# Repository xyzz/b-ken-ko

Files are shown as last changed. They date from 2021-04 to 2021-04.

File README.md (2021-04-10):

# b\*ken\*ko

A gummyworm mount case based on [Bakeneko 60](https://github.com/kkatano/bakeneko-60) by [kkatano](https://github.com/kkatano)

## Notes

* Case holes/threads for the daughterboard are a bit shallow, you might have to use 3mm M3 screws. Or increase hole depth in the model.
* The reworked PCB is using STM32F103, you will need an ST-Link ($2 from aliexpress) to flash the bootloader if you get it made.
* Production files for PCB and daughterboard use JLCPCB assembly, JLCPCB will not solder JST connectors for you so they are not included into the files, you will have to hand-solder the connector. If you use a different fab, make sure the JST connector is included into the BOM and position file (or you'll get semi-assembled PCBs).
* O-ring spec is AS568-263 (ID 7.234", CS 0.139" / ID 183.74mm, CS 3.53mm).
* As we're not allowed to use the Unikorn mounting points, note that the PCB mounting points are not compatible with Unikorn, neither the Unikorn-compatible PCBs (such as plain60-flex) are compatible with this case

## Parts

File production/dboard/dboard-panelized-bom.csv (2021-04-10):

Comment | Designator | Footprint | LCSC
Conn_01x04 | J2 | random-keyboard-parts:JST-SR-4
5.1k | R1,R2 | Resistor_SMD:R_0603_1608Metric | C23186
Mount-M2 | MH1,MH2 | MountingHole:MountingHole_3.2mm_M3_Pad_Via
1M | R3 | Resistor_SMD:R_0805_2012Metric | C17514
4.7n | C1 | Capacitor_SMD:C_0603_1608Metric | C53987
HRO-TYPE-C-31-M-12 | J1 | Type-C:HRO-TYPE-C-31-M-12-jlc | C165948

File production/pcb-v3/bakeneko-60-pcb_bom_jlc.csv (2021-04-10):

Comment | Designator | Footprint | LCSC Part #
1u | C1,C2,C10 | C_0603_1608Metric | C15849
20p | C4,C5 | C_0603_1608Metric | C1648
100n | C6,C7,C8,C9,C11,C3 | C_0603_1608Metric | C14663
10u | C12 | C_0603_1608Metric | C19702
1N4148 | D63,D62,D61,D60,D59,D58,D57,D56,D55,D54,D53,D52,D51,D50,D49,D48,D47,D46,D45,D44,D43,D42,D41,D40,D39,D38,D37,D36,D35,D34,D33,D32,D31,D30,D29,D28,D27,D26,D25,D24,D23,D22,D21,D20,D19,D18,D17,D16,D15,D14,D13,D12,D11,D10,D9,D8,D7,D6,D5,D4,D3,D2,D1 | D_SOD-123 | C81598
500mA | F1 | Fuse_1206_3216Metric | C369159
10k | R1 | R_0603_1608Metric | C25804
1.5k | R2 | R_0603_1608Metric | C22843
SRV05-4 | U1 | SOT-23-6 | C85364
XC6206P332MR | U2 | SOT-23 | C5446
STM32F103C8Tx | U3 | LQFP-48_7x7mm_P0.5mm | C8304
8MHz | Y1 | Crystal_SMD_5032-2Pin_5.0x3.2mm | C115962

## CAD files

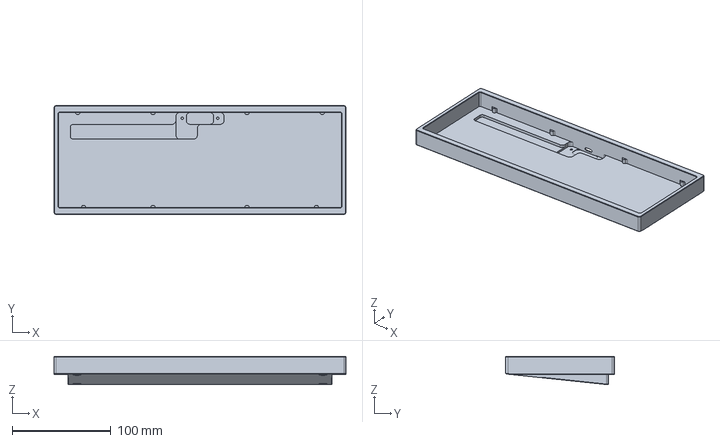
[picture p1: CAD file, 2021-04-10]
case/Case.stp
295.7 x 110.2 x 28.8 mm

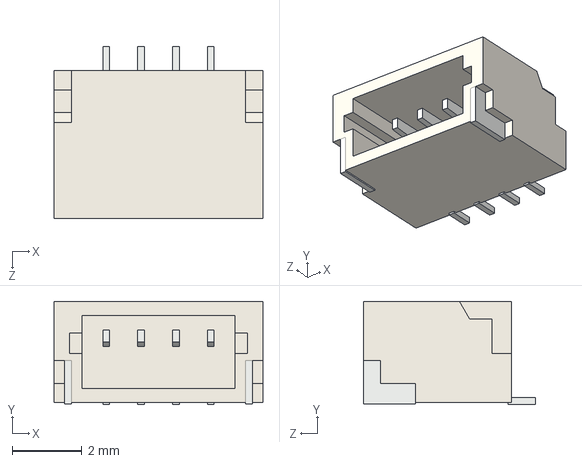
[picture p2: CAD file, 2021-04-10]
pcb/JST_SM04B-SRSS-TB.STEP
6.00 x 2.96 x 4.95 mm

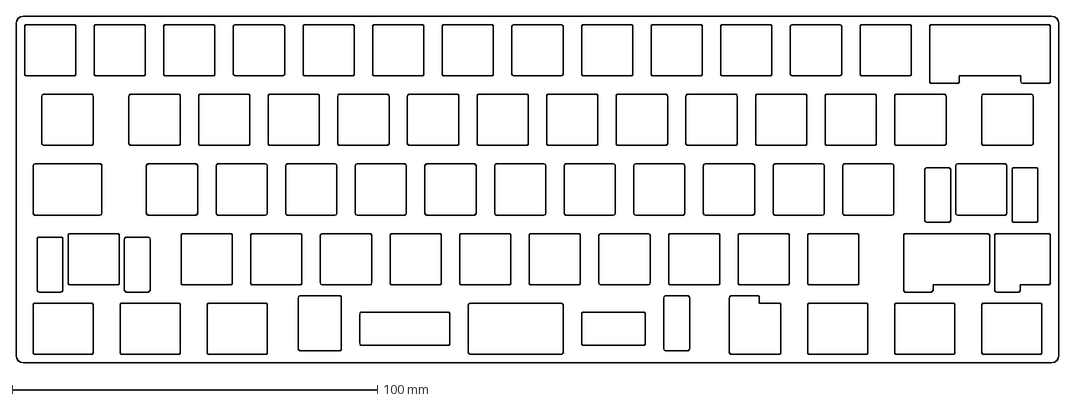
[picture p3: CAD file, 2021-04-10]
plate.dxf
285.4 x 94.8 mm

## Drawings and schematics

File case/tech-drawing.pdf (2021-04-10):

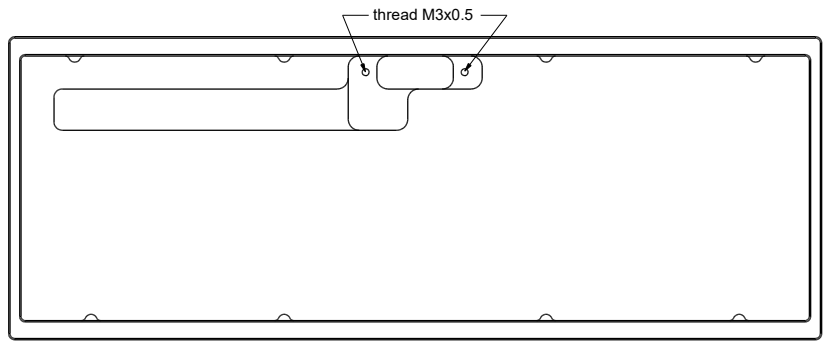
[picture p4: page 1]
thread M3x0.5

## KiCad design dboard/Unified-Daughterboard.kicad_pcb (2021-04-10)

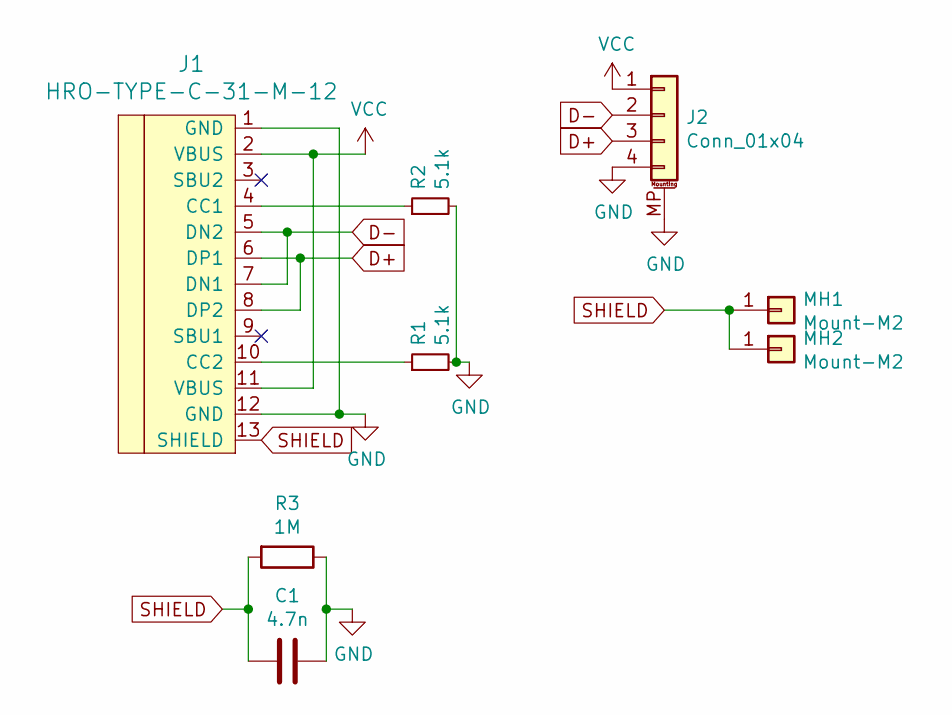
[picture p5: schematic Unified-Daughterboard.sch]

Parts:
C1: 4.7n; C_0603_1608Metric; LCSC C53987
J1: HRO-TYPE-C-31-M-12; HRO-TYPE-C-31-M-12-jlc; LCSC C165948
J2: Conn_01x04; JST-SR-4
MH1, MH2: Mount-M2; MountingHole_3.2mm_M3_Pad_Via
R1, R2: 5.1k; R_0603_1608Metric; LCSC C23186
R3: 1M; R_0805_2012Metric; LCSC C17514

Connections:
D+: J1.6 (DP1), J1.8 (DP2), J2.3
D-: J1.5 (DN2), J1.7 (DN1), J2.2
GND: C1.1, J1.1 (GND), J1.12 (GND), J2.4, J2.MP (MountPin), R1.2, R2.2, R3.1
unnamed: J1.4 (CC1), R2.1
unnamed: J1.10 (CC2), R1.1
SHIELD: C1.2, J1.13 (SHIELD), MH1.1, MH2.1, R3.2
VCC: J1.2 (VBUS), J1.11 (VBUS), J2.1

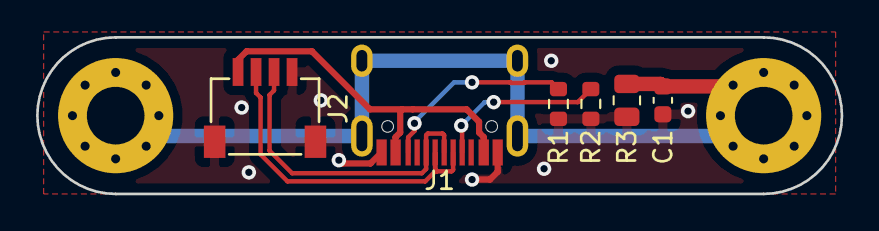
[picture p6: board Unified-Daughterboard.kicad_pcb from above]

Board: 2 copper layers, 44.7 x 8.7 mm, 8 parts (0 on the bottom side), 7 nets.

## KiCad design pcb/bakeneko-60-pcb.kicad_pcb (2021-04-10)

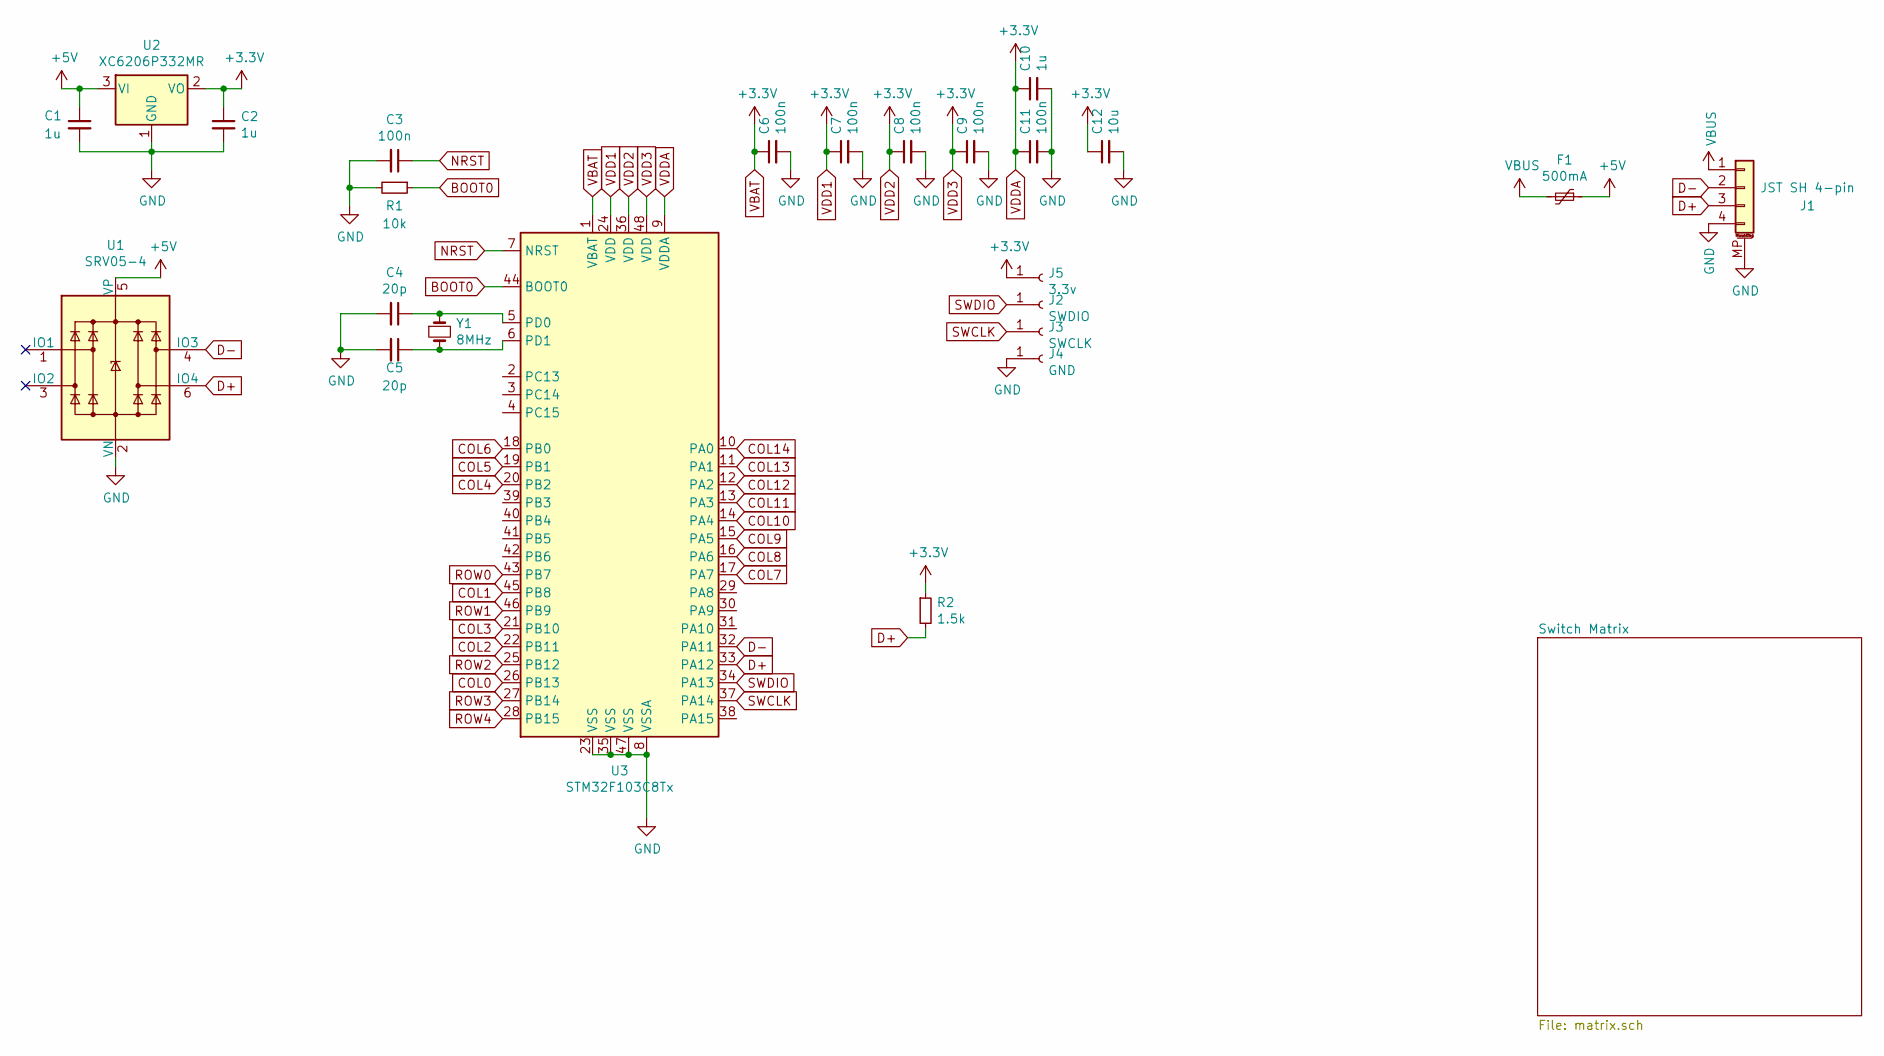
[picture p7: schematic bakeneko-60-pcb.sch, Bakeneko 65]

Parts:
C1, C2, C10: 1u; C_0603_1608Metric; JLC C15849
C3, C6, C7, C8, C9, C11: 100n; C_0603_1608Metric; JLC C14663
C4, C5: 20p; C_0603_1608Metric; JLC C1648
C12: 10u; C_0603_1608Metric; JLC C19702
F1: 500mA; Fuse_1206_3216Metric; JLC C369159
J1: JST SH 4-pin; JST_SH_SM04B-SRSS-TB_1x04-1MP_P1.00mm_Horizontal
J2: SWDIO; TestPoint_Pad_D1.5mm
J3: SWCLK; TestPoint_Pad_D1.5mm
J4: GND; TestPoint_Pad_D1.5mm
J5: 3.3v; TestPoint_Pad_D1.5mm
R1: 10k; R_0603_1608Metric; JLC C25804
R2: 1.5k; R_0603_1608Metric; JLC C22843
U1: SRV05-4; SOT-23-6; JLC C85364
U2: XC6206P332MR; SOT-23; JLC C5446
U3: STM32F103C8Tx; LQFP-48_7x7mm_P0.5mm; JLC C77979
Y1: 8MHz; Crystal_SMD_5032-2Pin_5.0x3.2mm; JLC C115962

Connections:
+5V: C1.1, F1.1, U1.5 (VP), U2.3 (VI)
BOOT0: R1.1, U3.44 (BOOT0)
COL0: U3.26 (PB13); also elsewhere on the board
COL1: U3.45 (PB8); also elsewhere on the board
COL2: U3.22 (PB11); also elsewhere on the board
COL3: U3.21 (PB10); also elsewhere on the board
COL4: U3.20 (PB2); also elsewhere on the board
COL5: U3.19 (PB1); also elsewhere on the board
COL6: U3.18 (PB0); also elsewhere on the board
COL7: U3.17 (PA7); also elsewhere on the board
COL8: U3.16 (PA6); also elsewhere on the board
COL9: U3.15 (PA5); also elsewhere on the board
COL10: U3.14 (PA4); also elsewhere on the board
COL11: U3.13 (PA3); also elsewhere on the board
COL12: U3.12 (PA2); also elsewhere on the board
COL13: U3.11 (PA1); also elsewhere on the board
COL14: U3.10 (PA0); also elsewhere on the board
D+: J1.3, R2.2, U1.6 (IO4), U3.33 (PA12)
D-: J1.2, U1.4 (IO3), U3.32 (PA11)
GND: C1.2, C2.2, C3.2, C4.2, C5.2, C6.2, C7.2, C8.2, C9.2, C10.2, C11.2, C12.2, J1.4, J1.MP (MountPin), J4.1, R1.2, U1.2 (VN), U2.1 (GND), U3.8 (VSSA), U3.23 (VSS), U3.35 (VSS), U3.47 (VSS)
NRST: C3.1, U3.7 (NRST)
unnamed: C4.1, U3.5 (PD0), Y1.1
unnamed: C5.1, U3.6 (PD1), Y1.2
ROW0: U3.43 (PB7); also elsewhere on the board
ROW1: U3.46 (PB9); also elsewhere on the board
ROW2: U3.25 (PB12); also elsewhere on the board
ROW3: U3.27 (PB14); also elsewhere on the board
ROW4: U3.28 (PB15); also elsewhere on the board
SWCLK: J3.1, U3.37 (PA14)
SWDIO: J2.1, U3.34 (PA13)
VBAT: C2.1, C6.1, C7.1, C8.1, C9.1, C10.1, C11.1, C12.1, J5.1, R2.1, U2.2 (VO), U3.1 (VBAT), U3.9 (VDDA), U3.24 (VDD), U3.36 (VDD), U3.48 (VDD)
VBUS: F1.2, J1.1

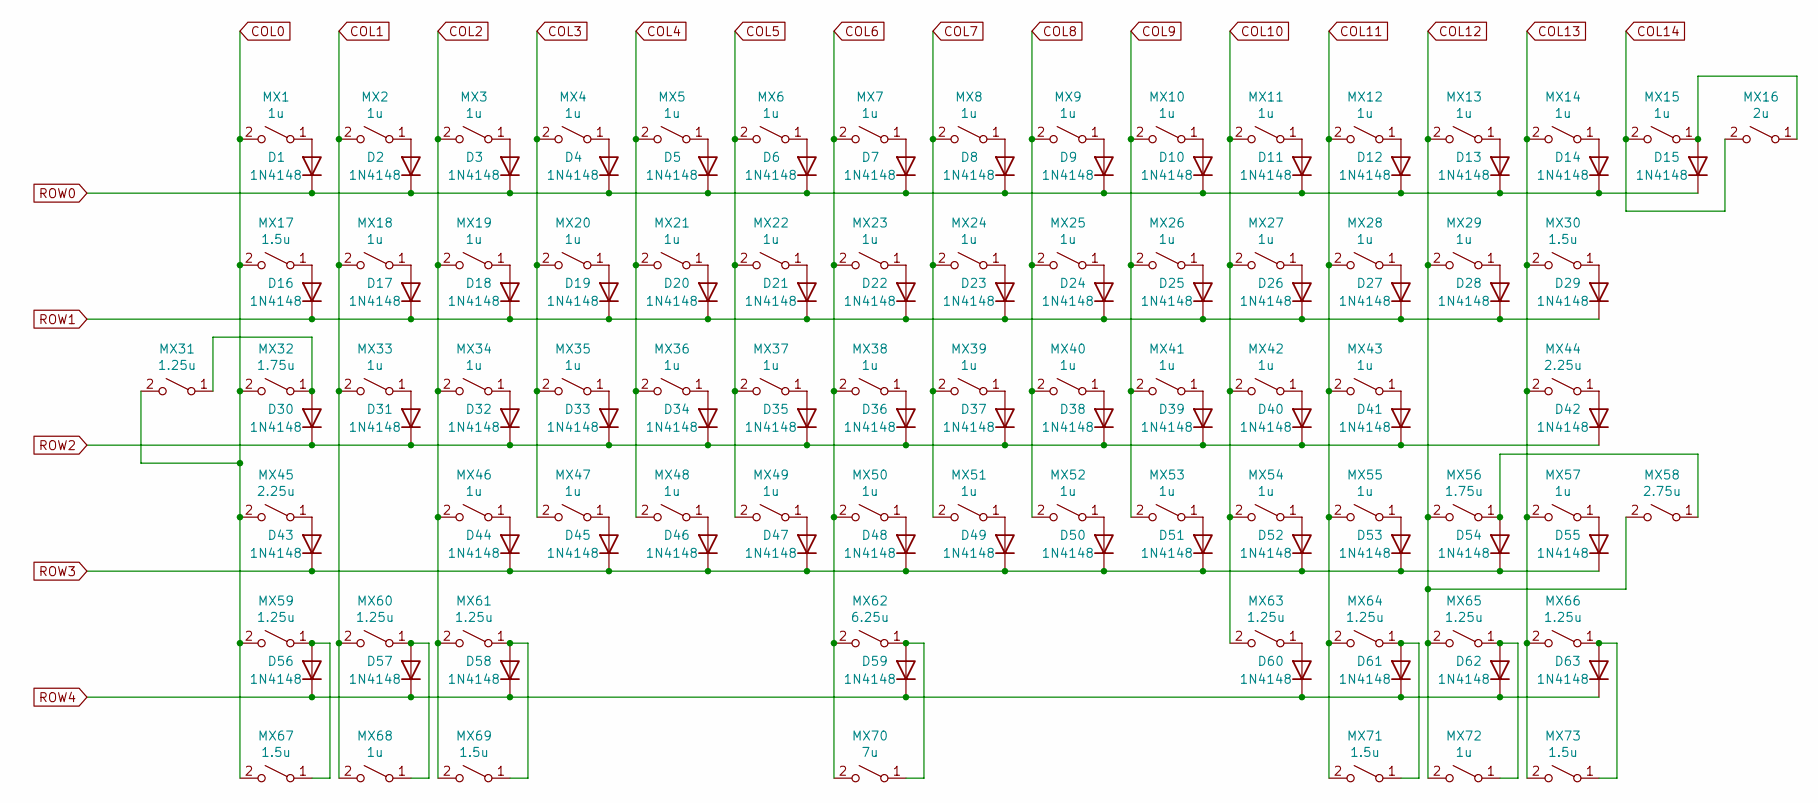
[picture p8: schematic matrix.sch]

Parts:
D1, D2, D3, D4, D5, D6, D7, D8, D9, D10, D11, D12, D13, D14, D15, D16, D17, D18, D19, D20, D21, D22, D23, D24, D25, D26, D27, D28, D29, D30, D31, D32, D33, D34, D35, D36, D37, D38, D39, D40, D41, D42, D43, D44, D45, D46, D47, D48, D49, D50, D51, D52, D53, D54, D55, D56, D57, D58, D59, D60, D61, D62, D63: 1N4148; D_SOD-123; JLC C81598
MX1, MX2, MX3, MX4, MX5, MX6, MX7, MX8, MX9, MX10, MX11, MX12, MX13, MX14, MX15, MX18, MX19, MX20, MX21, MX22, MX23, MX24, MX25, MX26, MX27, MX28, MX29, MX33, MX34, MX35, MX36, MX37, MX38, MX39, MX40, MX41, MX42, MX43, MX46, MX47, MX48, MX49, MX50, MX51, MX52, MX53, MX54, MX55, MX57, MX68, MX72: 1u; MXOnly-1U-NoLED
MX16: 2u; MXOnly-2U-NoLED
MX17, MX30, MX67, MX69, MX71, MX73: 1.5u; MXOnly-1.5U-NoLED
MX31, MX59, MX60, MX61, MX63, MX64, MX65, MX66: 1.25u; MXOnly-1.25U-NoLED
MX32, MX56: 1.75u; MXOnly-1.75U-NoLED
MX44, MX45: 2.25u; MXOnly-2.25U-NoLED
MX58: 2.75u; MXOnly-2.75U-NoLED
MX62: 6.25u; MXOnly-6.25U-ReversedStabilizers-NoLED
MX70: 7u; MXOnly-7U-ReversedStabilizers-NoLED

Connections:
COL0: MX1.2 (B), MX17.2 (B), MX31.2 (B), MX32.2 (B), MX45.2 (B), MX59.2 (B), MX67.2 (B); also elsewhere on the board
COL1: MX2.2 (B), MX18.2 (B), MX33.2 (B), MX60.2 (B), MX68.2 (B); also elsewhere on the board
COL2: MX3.2 (B), MX19.2 (B), MX34.2 (B), MX46.2 (B), MX61.2 (B), MX69.2 (B); also elsewhere on the board
COL3: MX4.2 (B), MX20.2 (B), MX35.2 (B), MX47.2 (B); also elsewhere on the board
COL4: MX5.2 (B), MX21.2 (B), MX36.2 (B), MX48.2 (B); also elsewhere on the board
COL5: MX6.2 (B), MX22.2 (B), MX37.2 (B), MX49.2 (B); also elsewhere on the board
COL6: MX7.2 (B), MX23.2 (B), MX38.2 (B), MX50.2 (B), MX62.2 (B), MX70.2 (B); also elsewhere on the board
COL7: MX8.2 (B), MX24.2 (B), MX39.2 (B), MX51.2 (B); also elsewhere on the board
COL8: MX9.2 (B), MX25.2 (B), MX40.2 (B), MX52.2 (B); also elsewhere on the board
COL9: MX10.2 (B), MX26.2 (B), MX41.2 (B), MX53.2 (B); also elsewhere on the board
COL10: MX11.2 (B), MX27.2 (B), MX42.2 (B), MX54.2 (B), MX63.2 (B); also elsewhere on the board
COL11: MX12.2 (B), MX28.2 (B), MX43.2 (B), MX55.2 (B), MX64.2 (B), MX71.2 (B); also elsewhere on the board
COL12: MX13.2 (B), MX29.2 (B), MX56.2 (B), MX58.2 (B), MX65.2 (B), MX72.2 (B); also elsewhere on the board
COL13: MX14.2 (B), MX30.2 (B), MX44.2 (B), MX57.2 (B), MX66.2 (B), MX73.2 (B); also elsewhere on the board
COL14: MX15.2 (B), MX16.2 (B); also elsewhere on the board
unnamed: D1.2 (A), MX1.1 (A)
unnamed: D2.2 (A), MX2.1 (A)
unnamed: D3.2 (A), MX3.1 (A)
unnamed: D4.2 (A), MX4.1 (A)
unnamed: D5.2 (A), MX5.1 (A)
unnamed: D6.2 (A), MX6.1 (A)
unnamed: D7.2 (A), MX7.1 (A)
unnamed: D8.2 (A), MX8.1 (A)
unnamed: D9.2 (A), MX9.1 (A)
unnamed: D10.2 (A), MX10.1 (A)
unnamed: D11.2 (A), MX11.1 (A)
unnamed: D12.2 (A), MX12.1 (A)
unnamed: D13.2 (A), MX13.1 (A)
unnamed: D14.2 (A), MX14.1 (A)
unnamed: D15.2 (A), MX15.1 (A), MX16.1 (A)
unnamed: D16.2 (A), MX17.1 (A)
unnamed: D17.2 (A), MX18.1 (A)
unnamed: D18.2 (A), MX19.1 (A)
unnamed: D19.2 (A), MX20.1 (A)
unnamed: D20.2 (A), MX21.1 (A)
unnamed: D21.2 (A), MX22.1 (A)
unnamed: D22.2 (A), MX23.1 (A)
unnamed: D23.2 (A), MX24.1 (A)
unnamed: D24.2 (A), MX25.1 (A)
unnamed: D25.2 (A), MX26.1 (A)
unnamed: D26.2 (A), MX27.1 (A)
unnamed: D27.2 (A), MX28.1 (A)
unnamed: D28.2 (A), MX29.1 (A)
unnamed: D29.2 (A), MX30.1 (A)
unnamed: D30.2 (A), MX31.1 (A), MX32.1 (A)
unnamed: D31.2 (A), MX33.1 (A)
unnamed: D32.2 (A), MX34.1 (A)
unnamed: D33.2 (A), MX35.1 (A)
unnamed: D34.2 (A), MX36.1 (A)
unnamed: D35.2 (A), MX37.1 (A)
unnamed: D36.2 (A), MX38.1 (A)
unnamed: D37.2 (A), MX39.1 (A)
unnamed: D38.2 (A), MX40.1 (A)
unnamed: D39.2 (A), MX41.1 (A)
unnamed: D40.2 (A), MX42.1 (A)
unnamed: D41.2 (A), MX43.1 (A)
unnamed: D42.2 (A), MX44.1 (A)
unnamed: D43.2 (A), MX45.1 (A)
unnamed: D44.2 (A), MX46.1 (A)
unnamed: D45.2 (A), MX47.1 (A)
unnamed: D46.2 (A), MX48.1 (A)
unnamed: D47.2 (A), MX49.1 (A)
unnamed: D48.2 (A), MX50.1 (A)
unnamed: D49.2 (A), MX51.1 (A)
unnamed: D50.2 (A), MX52.1 (A)
unnamed: D51.2 (A), MX53.1 (A)
unnamed: D52.2 (A), MX54.1 (A)
unnamed: D53.2 (A), MX55.1 (A)
unnamed: D54.2 (A), MX56.1 (A), MX58.1 (A)
unnamed: D55.2 (A), MX57.1 (A)
unnamed: D56.2 (A), MX59.1 (A), MX67.1 (A)
unnamed: D57.2 (A), MX60.1 (A), MX68.1 (A)
unnamed: D58.2 (A), MX61.1 (A), MX69.1 (A)
unnamed: D59.2 (A), MX62.1 (A), MX70.1 (A)
unnamed: D60.2 (A), MX63.1 (A)
unnamed: D61.2 (A), MX64.1 (A), MX71.1 (A)
unnamed: D62.2 (A), MX65.1 (A), MX72.1 (A)
unnamed: D63.2 (A), MX66.1 (A), MX73.1 (A)
ROW0: D1.1 (K), D2.1 (K), D3.1 (K), D4.1 (K), D5.1 (K), D6.1 (K), D7.1 (K), D8.1 (K), D9.1 (K), D10.1 (K), D11.1 (K), D12.1 (K), D13.1 (K), D14.1 (K), D15.1 (K); also elsewhere on the board
ROW1: D16.1 (K), D17.1 (K), D18.1 (K), D19.1 (K), D20.1 (K), D21.1 (K), D22.1 (K), D23.1 (K), D24.1 (K), D25.1 (K), D26.1 (K), D27.1 (K), D28.1 (K), D29.1 (K); also elsewhere on the board
ROW2: D30.1 (K), D31.1 (K), D32.1 (K), D33.1 (K), D34.1 (K), D35.1 (K), D36.1 (K), D37.1 (K), D38.1 (K), D39.1 (K), D40.1 (K), D41.1 (K), D42.1 (K); also elsewhere on the board
ROW3: D43.1 (K), D44.1 (K), D45.1 (K), D46.1 (K), D47.1 (K), D48.1 (K), D49.1 (K), D50.1 (K), D51.1 (K), D52.1 (K), D53.1 (K), D54.1 (K), D55.1 (K); also elsewhere on the board
ROW4: D56.1 (K), D57.1 (K), D58.1 (K), D59.1 (K), D60.1 (K), D61.1 (K), D62.1 (K), D63.1 (K); also elsewhere on the board

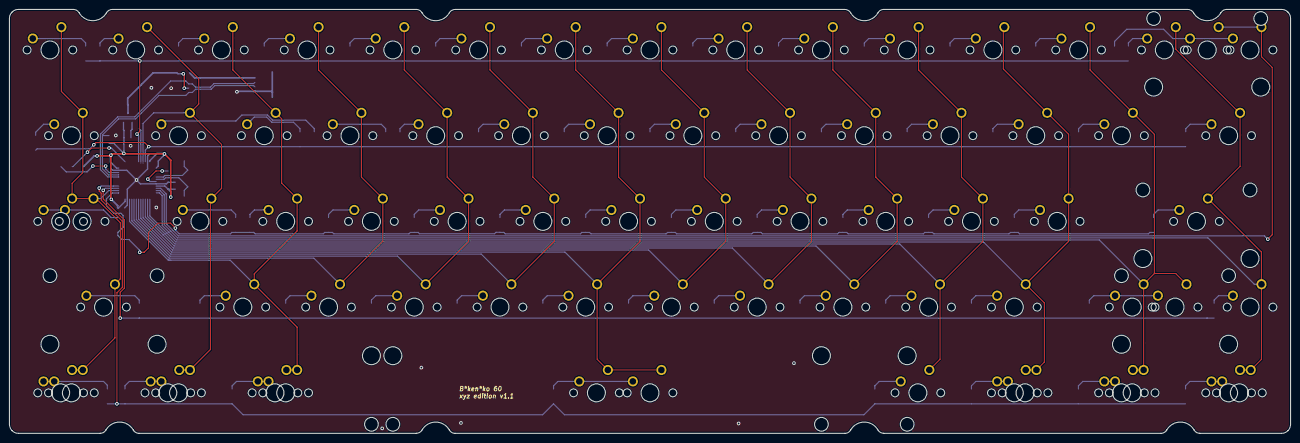
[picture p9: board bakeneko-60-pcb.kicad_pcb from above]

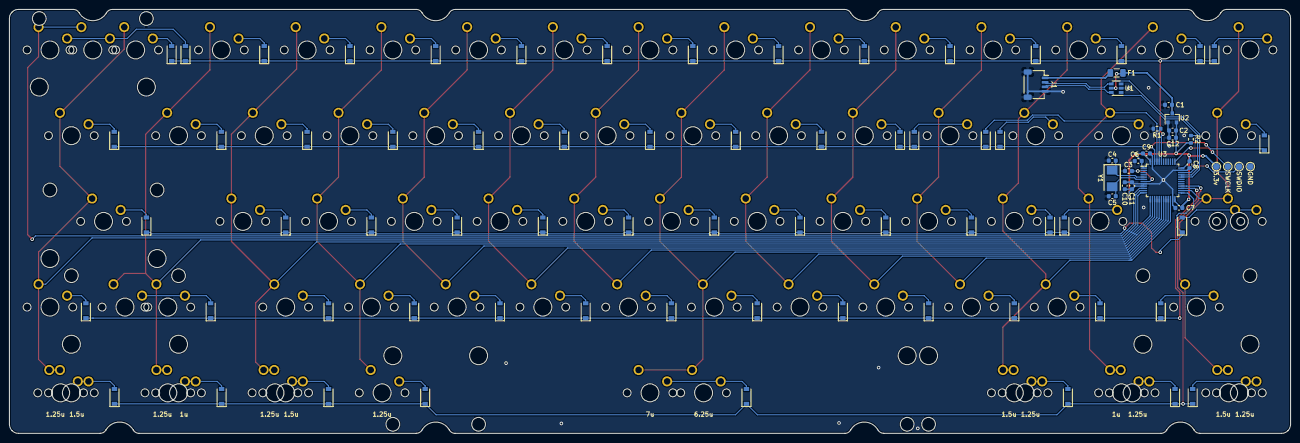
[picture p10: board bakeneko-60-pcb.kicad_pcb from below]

Board: 2 copper layers, 284.7 x 94.2 mm, 160 parts (87 on the bottom side), 95 nets.
